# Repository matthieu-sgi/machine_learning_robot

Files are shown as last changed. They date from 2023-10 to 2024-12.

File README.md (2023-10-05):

# Machine learning robot

The machine learning bot is a project of making an OpenSource robot that will be able to learn from its environment and adapt to it using machine learning.

The robot is based on a FREENOVE ESP32 S3 MCU and its camera. It also includes a LIDAR.
The mechanical part is based on a Adafruit 3216 chassis.

## Electronics

### Electronics components

The robot is based on a [FREENOVE ESP32 S3](https://github.com/Freenove/Freenove_ESP32_S3_WROOM_Board).

In addition to the included camera, we bought [this camera](https://www.amazon.fr/gp/product/B0BXSL76L8/ref=ewc_pr_img_1?smid=AFDYUAFSP3DOA&psc=1). The ribbon cable is longer than the included one and it allows to position it on the front of the robot.

The LIDAR used is a LD06 from innomaker ([datasheet](https://www.inno-maker.com/wp-content/uploads/2020/11/LDROBOT_LD06_Datasheet.pdf)).

### PCB

The chassis chosen is very tiny. It includes only two frame for two stages. To gain space, we decided to build and make a full PCB stage. Allowing the robot to go from 2 to 3 stages.

The PCB project can be found in the [pcb](https://github.com/matthieu-sgi/machine_learning_robot/tree/main/PCB) folder.

3D view of the PCB:

Front 3D view | Back 3D view
:------------:|:------------:
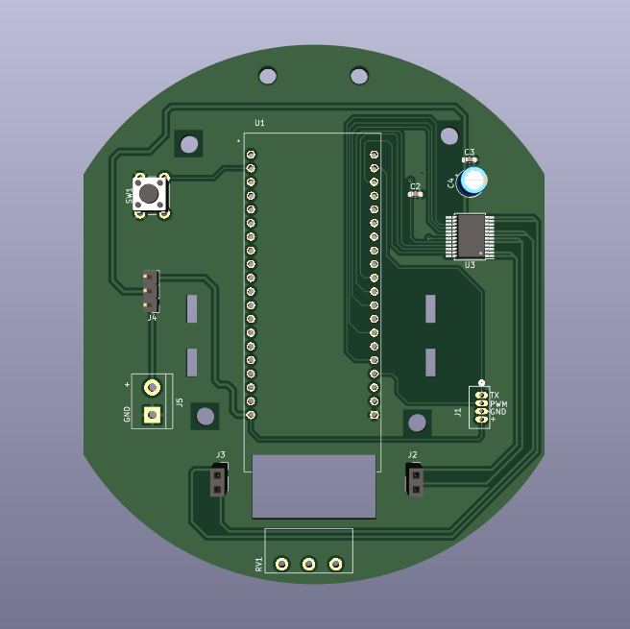
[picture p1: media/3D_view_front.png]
Front 3D view
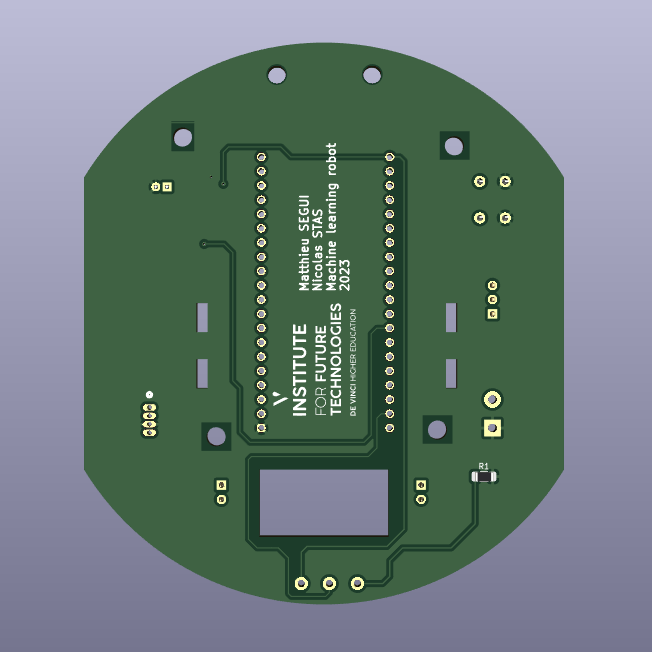
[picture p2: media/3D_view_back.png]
Back 3D view
 |

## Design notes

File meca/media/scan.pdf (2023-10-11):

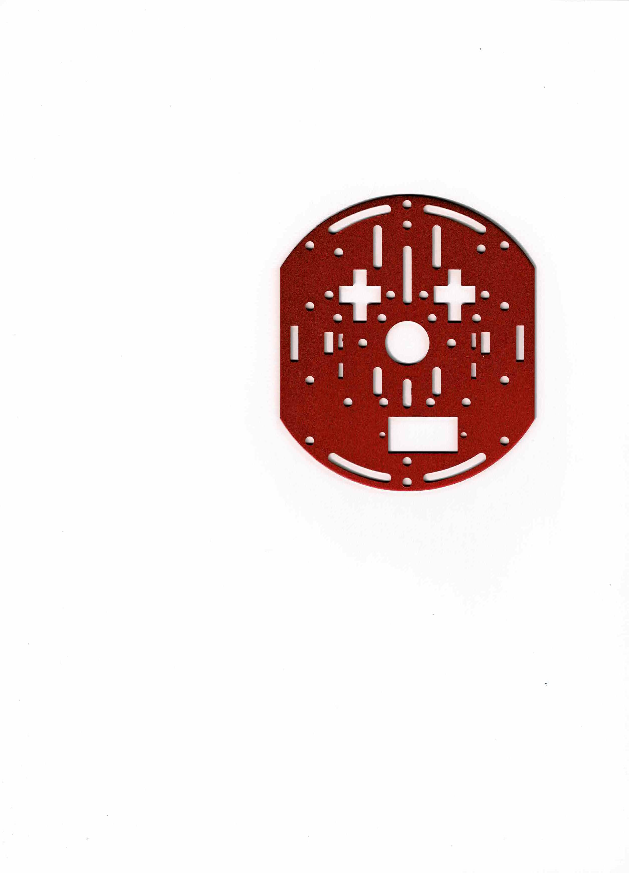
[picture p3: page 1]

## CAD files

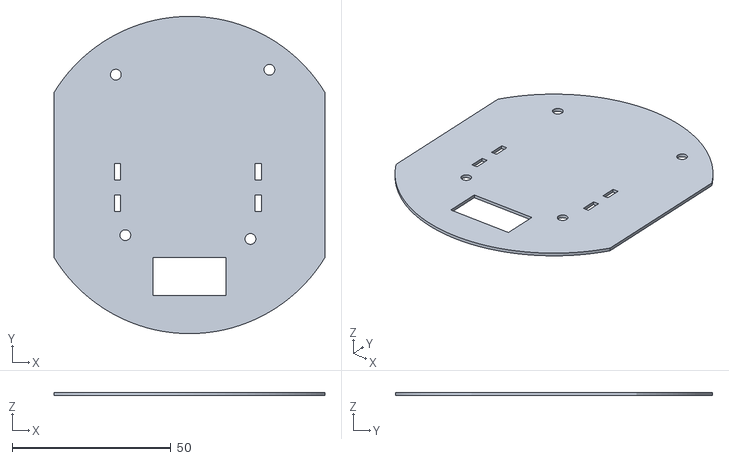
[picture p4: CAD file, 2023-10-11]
meca/etage-Body.stl
85.4 x 100.0 x 1.00

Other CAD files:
meca/etage.FCStd
meca/etage-Body.dxf

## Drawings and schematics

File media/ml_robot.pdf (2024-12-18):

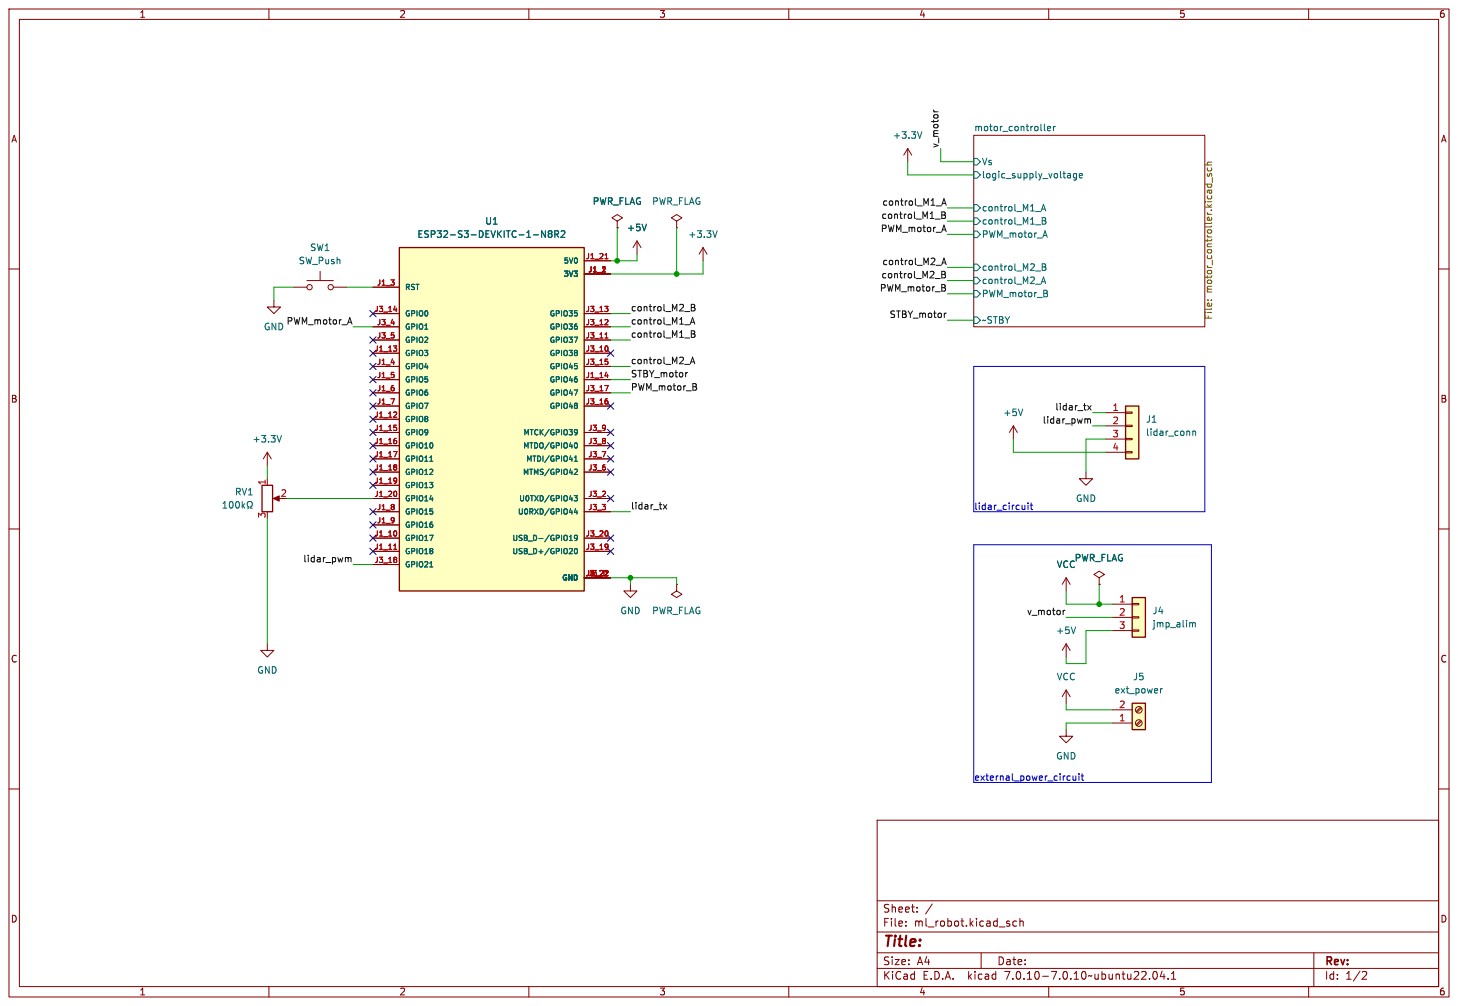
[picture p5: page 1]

Id: 1/2 Title: File: ml_robot.kicad_sch Sheet: /

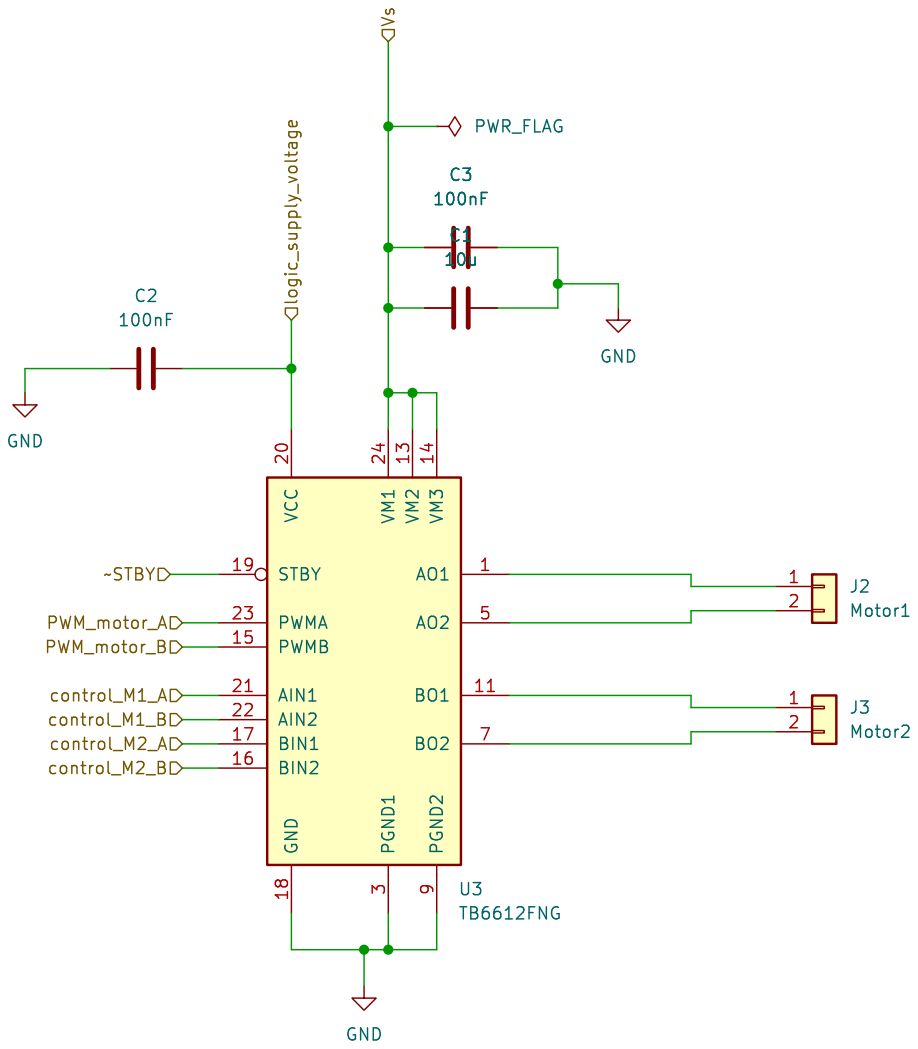
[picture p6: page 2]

Id: 2/2 Title: File: motor_controller.kicad_sch Sheet: /motor_controller/

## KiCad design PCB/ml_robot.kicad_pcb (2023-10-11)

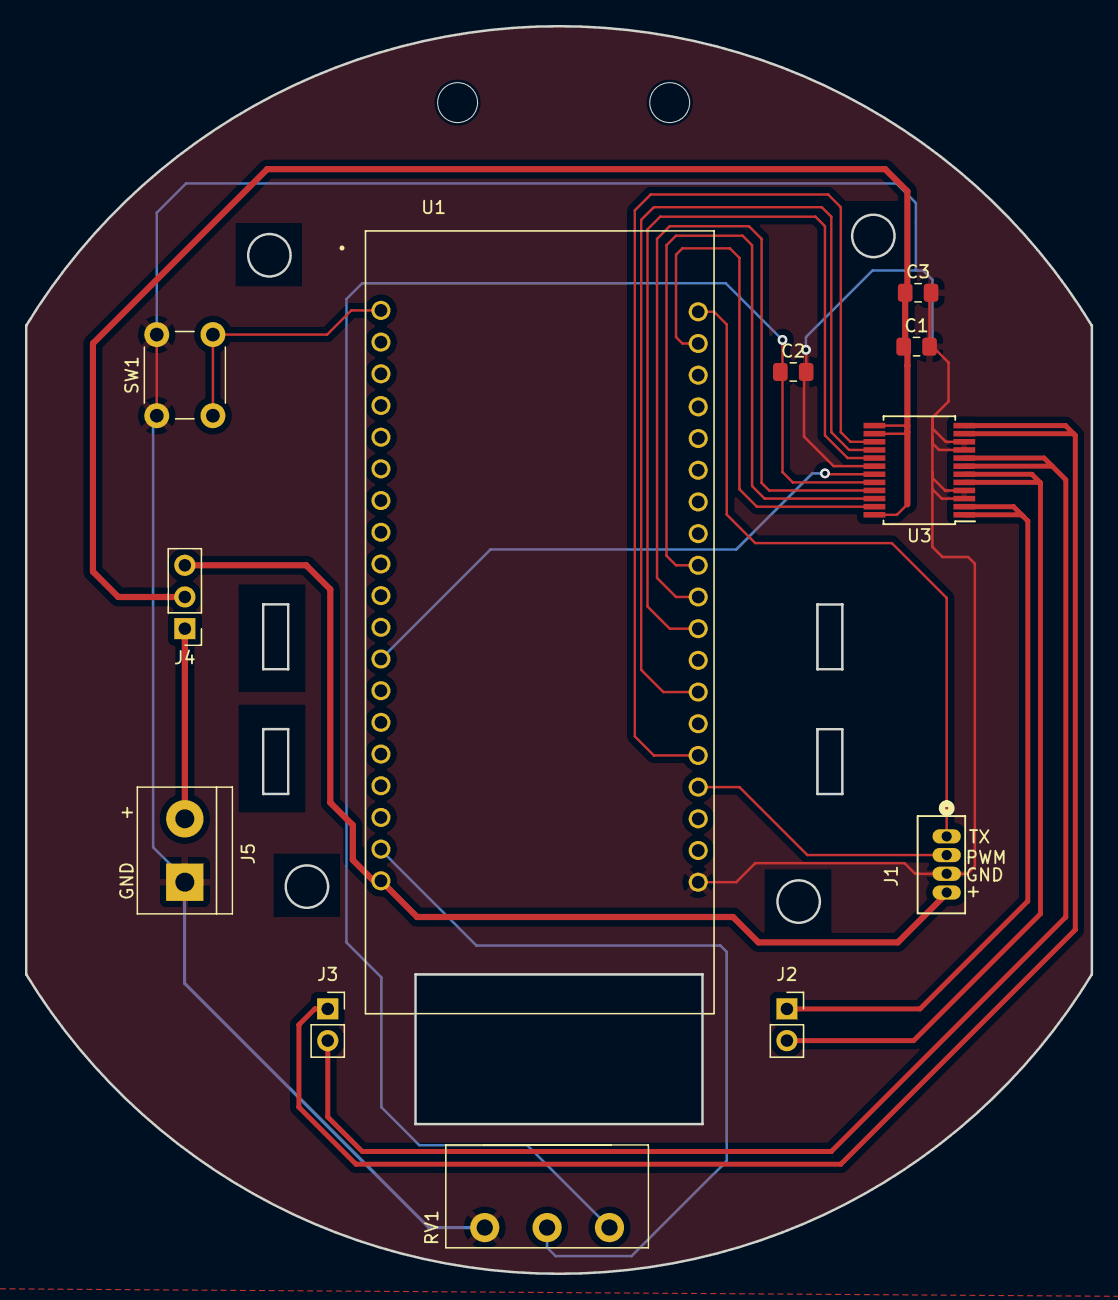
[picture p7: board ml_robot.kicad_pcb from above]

Board: 2 copper layers, 85.4 x 100.0 mm, 12 parts (0 on the bottom side), 20 nets.

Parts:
C1: 10u; C_0805_2012Metric_Pad1.18x1.45mm_HandSolder
C2, C3: 100nF; C_0805_2012Metric_Pad1.18x1.45mm_HandSolder
J1: lidar_conn; CONN_B4B-ZR_LF__SN__JST
J2: Motor1; PinSocket_1x02_P2.54mm_Vertical
J3: Motor2; PinSocket_1x02_P2.54mm_Vertical
J4: jmp_alim; PinHeader_1x03_P2.54mm_Vertical
J5: ext_power; TerminalBlock_bornier-2_P5.08mm
RV1: 100kΩ; Potentiometer_Piher_PC-16_Single_Horizontal
SW1: SW_Push; SW_PUSH_6mm
U1: ESP32-S3-DEVKITC-1-N8R2; XCVR_ESP32-S3-DEVKITC-1-N8R2
U3: TB6612FNG; SSOP-24_5.3x8.2mm_P0.65mm

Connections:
+3V3: C2.1, RV1.1, U3.20 (VCC)
+5V: J1.4, J4.3, U1.J1_21 (5V0)
/PWM_motor_A: U1.J3_4 (GPIO1), U3.23 (PWMA)
/PWM_motor_B: U1.J3_17 (GPIO47), U3.15 (PWMB)
/STBY_motor: U1.J1_14 (GPIO46), U3.19 (STBY)
/control_M1_A: U1.J3_12 (GPIO36), U3.21 (AIN1)
/control_M1_B: U1.J3_11 (GPIO37), U3.22 (AIN2)
/control_M2_A: U1.J3_15 (GPIO45), U3.16 (BIN2)
/control_M2_B: U1.J3_13 (GPIO35), U3.17 (BIN1)
/lidar_pwm: J1.2, U1.J3_18 (GPIO21)
/lidar_tx: J1.1, U1.J3_3 (U0RXD/GPIO44)
/v_motor: C1.1, C3.1, J4.2, U3.13 (VM2), U3.14 (VM3), U3.24 (VM1)
GND: C1.2, C2.2, C3.2, J1.3, J5.1, RV1.3, SW1.1, U1.J3_21 (GND), U3.3 (PGND1), U3.4 (PGND1), U3.9 (PGND2), U3.10 (PGND2), U3.18 (GND)
unnamed: J2.1, U3.1 (AO1), U3.2 (AO1)
unnamed: J2.2, U3.5 (AO2), U3.6 (AO2)
unnamed: J3.1, U3.11 (BO1), U3.12 (BO1)
unnamed: J3.2, U3.7 (BO2), U3.8 (BO2)
unnamed: RV1.2, U1.J1_20 (GPIO14)
unnamed: SW1.2, U1.J1_3 (RST)
VCC: J4.1, J5.2

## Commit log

2023-10-05 Adding PCB design
    [ml_robot.kicad_pcb, ml_robot.kicad_sch, motor_controller.kicad_sch]
2023-10-05 Adding exclusion zones
    [ml_robot.kicad_pcb]
2023-10-11 PCB version to fab
    [ml_robot.kicad_pcb, ml_robot.kicad_sch, motor_controller.kicad_sch]
2023-10-11 Adding platform mechanical schematic
    [etage-Body.dxf, etage-Body.stl, etage.FCStd]
